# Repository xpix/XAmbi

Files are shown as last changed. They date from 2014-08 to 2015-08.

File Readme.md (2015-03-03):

XAmbi Network
----------------
By Frank Herrmann (xpixer@gmail.com)
<br/>
XAmbi Network with Atmel Attiny and RFM12B

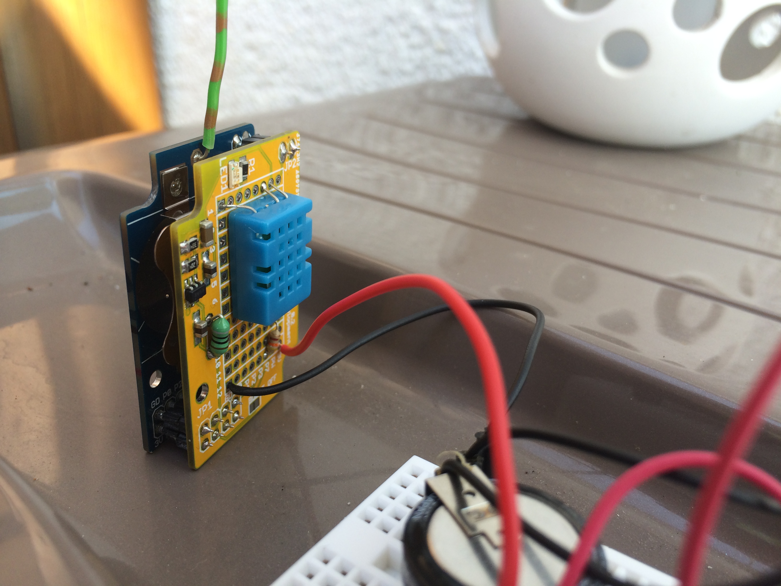
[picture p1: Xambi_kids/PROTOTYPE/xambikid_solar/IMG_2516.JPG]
XAmbi_kid_dht11


##Synopsis
The XAmbi Network system are a bunch of Sensor nodes and a Raspberry Gateway. This can control everything in your house and get the data in a nice Webinterface.
This is the Hardware section, here the Software part: [Webinterface](https://github.com/xpix/xambiserver) with MQTT Support. 

What do you need for the first start are follow components:
- a [RaspberryPi](http://en.wikipedia.org/wiki/Raspberry_Pi) with installed [git](http://en.wikipedia.org/wiki/Git_(software))
- a [Jeenode](http://jeelabs.net/projects/hardware/wiki/JeeNode) connected via USB or Serial to RPI
- one or more [xambi sensor](https://github.com/xpix/XAmbi/tree/master/Xambi_kids/xambikid_mainboard) nodes with an RFM12B Transceiver

##Features
- the xambi network system are very modular
- one Gateway with max 999 nodes
- very low bit rate for stable and long range communicaton via [Jeelib](http://jeelabs.net/pub/docs/jeelib/)
- sensor board a kind of breadboard to connect sensors very easy
- Boost to 3.3V on sensor board to get all energy from battery cell
- mainboard very small and standard sizes for normal enclousures

##Examples
- DHT11 [temperature and humidity Sensor](https://github.com/xpix/XAmbi/tree/master/Xambi_kids/xambikid_dht11)
- Dalles DS18B20 [Temperature Sensor](https://github.com/xpix/XAmbi/tree/master/Xambi_kids/xambikid_DS18B20)
- [Mailbox Sensor](https://github.com/xpix/XAmbi/tree/master/Xambi_kids/xambikid_mailbox) via infrared reflection
- Plant [Moisture Sensor](https://github.com/xpix/XAmbi/tree/master/Xambi_kids/xambikid_moisture)

##License
GPL 3.0. See License.txt file.

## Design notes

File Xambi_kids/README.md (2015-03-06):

XAmbi Kids
----------------
By Frank Herrmann (xpixer@gmail.com)
<br/>
XAmbi Network with Atmel Attiny and RFM12B

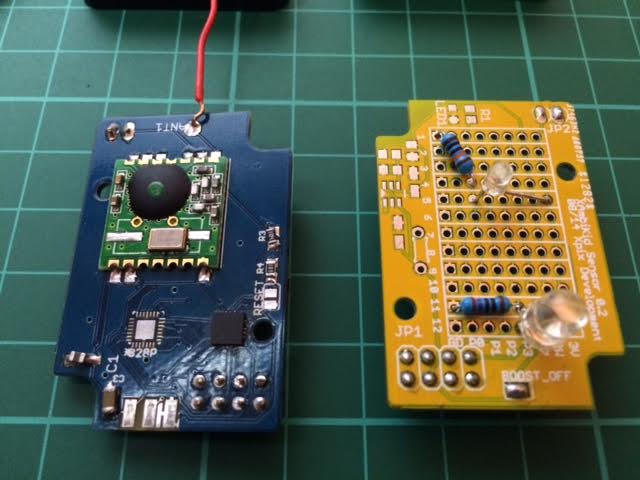
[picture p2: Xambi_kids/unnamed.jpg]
XAmbi_kid_mailbox


The XAmbi_Kids are sensors with an Attiny84 and a Transceiver RFM12B or for a cheaper solutuion with a infrared send led. 

##Features:

* small power consumtion. i.e. send every 5min a packet, run 1 year with a CR2032 battery cell
* send via serial with 2400 baud/s
* range up to ~15m in house
* range up to ~80m over the air
* cheap solution
* send via IR LED if you want and a revceiver exists
* small footprint (3x5cm)
* sensorboard with optional booster (1.5V => 3.3V or 5V)

##Hardware:

A xambi kid has 2 PCB's, they are stacked together. I call this [XAmbi-Mainboard](https://github.com/xpix/XAmbi/tree/master/Xambi_kids/xambikid_mainboard) and [XAmbi-Sensorboard](https://github.com/xpix/XAmbi/tree/master/Xambi_kids/xambikid_sensorboard). 
They are designed for a plastik enclouser [PDF Datasheet](https://cdn-reichelt.de/documents/datenblatt/C700/DS_1551G.pdf), they are standard and very cheap ~$2. We have to drill a hole for the antenna and thats all. 

##Software:

- DHT11 [temperature and humidity Sensor](https://github.com/xpix/XAmbi/tree/master/Xambi_kids/xambikid_dht11)
- Dalles DS18B20 [Temperature Sensor](https://github.com/xpix/XAmbi/tree/master/Xambi_kids/xambikid_DS18B20)
- [Mailbox Sensor](https://github.com/xpix/XAmbi/tree/master/Xambi_kids/xambikid_mailbox) via infrared reflection
- Plant [Moisture Sensor](https://github.com/xpix/XAmbi/tree/master/Xambi_kids/xambikid_moisture)

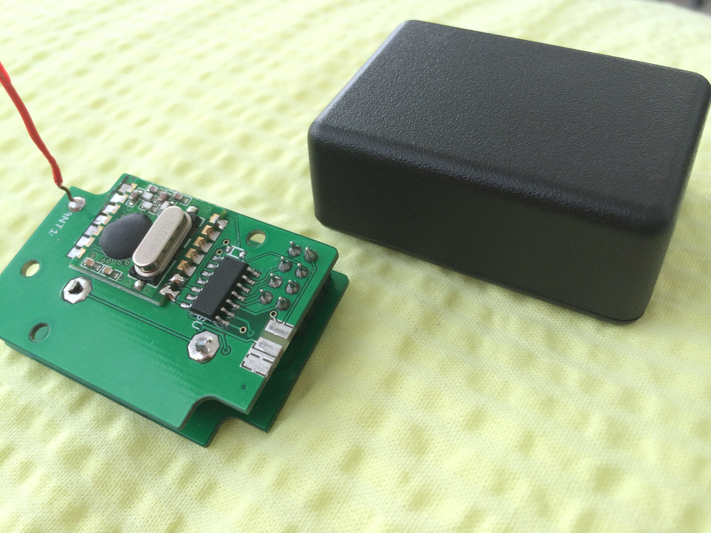
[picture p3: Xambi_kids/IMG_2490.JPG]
XAmbi_kid_dht11


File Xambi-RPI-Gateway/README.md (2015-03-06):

XAmbi Gateway for Raspberry PI
----------------
By Frank Herrmann (xpixer@gmail.com)
<br/>
RPI Shield with Atmega329P and RFM12B Transceiver 

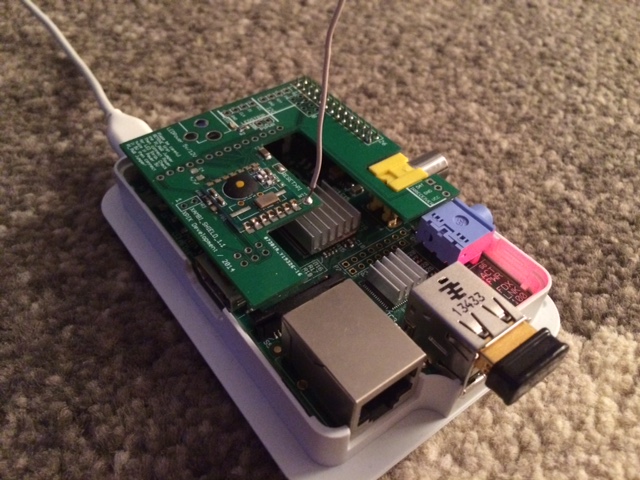
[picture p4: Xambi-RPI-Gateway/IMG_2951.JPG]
XAmbi_gateway


Here you find all the design for the Shield, on the pic you see the first Prototype. You can also connect a WS2812 LED Strip to install an Ambilight to your TV. But the first function from this board are a kind of [Jeenode](http://www.digitalsmarties.net/products/jeenode). 

* Solder an RF12B Board and Atmega with Quartz and other Components
* burn the fuses over ISCP and an Bootloader (Arduino UNO) to Atmega: [Tutorial](http://playground.arduino.cc/Learning/Burn168)
* Connect the board with an Raspberry PI
* Use the bootloader and burn the [simple receiver](https://github.com/xpix/XAmbi/tree/master/Xambi_kids/xambikid_simplereceiver) to the XAmbi Board
* connect via screen command and check for the "Init ..." text

You can use this Wiki: http://wiki.openenergymonitor.org/index.php?title=RFM12Pi_V2 they describe very good the steps to burn some firmware to an Arduno clone. This "Xambi-Gateway" are a arduino clone at the internal serial Line from Raspberry.

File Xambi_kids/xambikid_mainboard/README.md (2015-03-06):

XAmbi MainBoard
----------------
By Frank Herrmann (xpixer@gmail.com)
<br/>

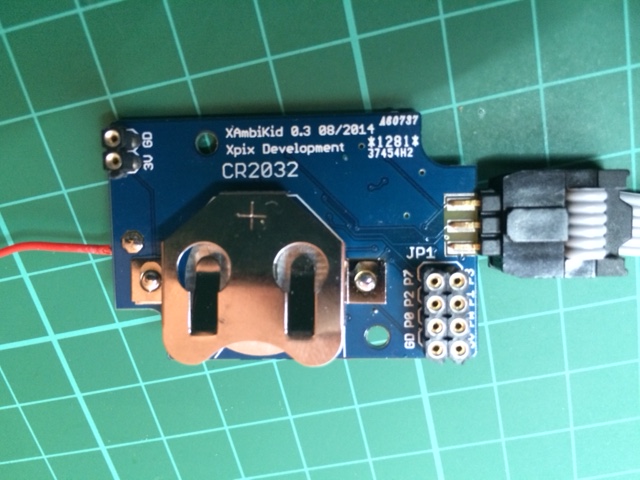
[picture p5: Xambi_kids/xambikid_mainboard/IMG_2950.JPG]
XAmbi-MainBoard

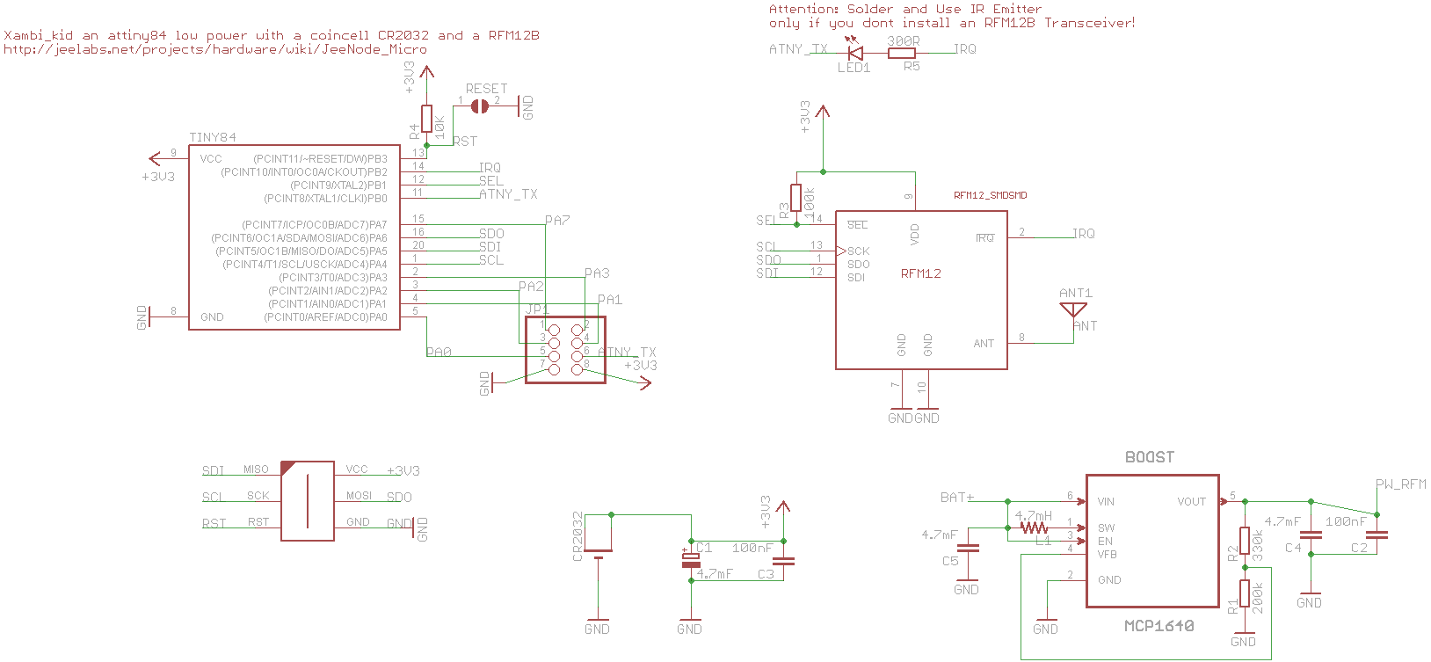
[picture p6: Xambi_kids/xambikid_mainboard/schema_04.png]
Schema 0.4

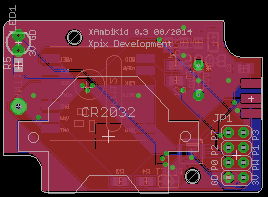
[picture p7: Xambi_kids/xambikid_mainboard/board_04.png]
Board 0.4


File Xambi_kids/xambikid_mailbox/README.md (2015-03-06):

XAmbi Mailbox IR Sensor
----------------
By Frank Herrmann (xpixer@gmail.com)
<br/>
XAmbi Network with Atmel Attiny and RFM12B

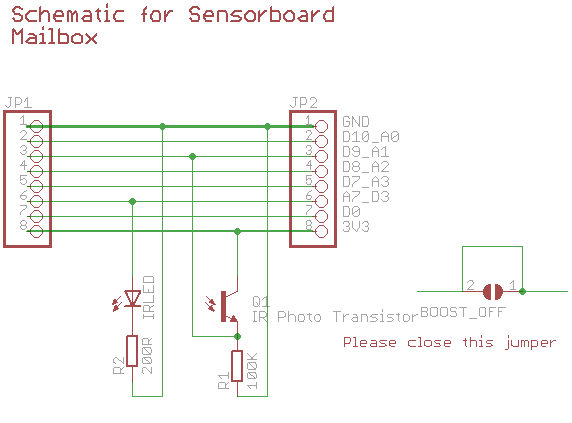
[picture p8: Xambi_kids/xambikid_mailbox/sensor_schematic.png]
XAmbi_moisture


##Synopsis
You can use this as mailbox Sensor. Via infred reflection to know is the box filled or empty.
This Sensor need Phototransistor and a IR LED. 
Please close the BOOST_OFF Jumper on Sensorboard.

##Youtube
* https://www.youtube.com/watch?v=9TAJDRMopDI

##License
GPL 3.0. See License.txt file.

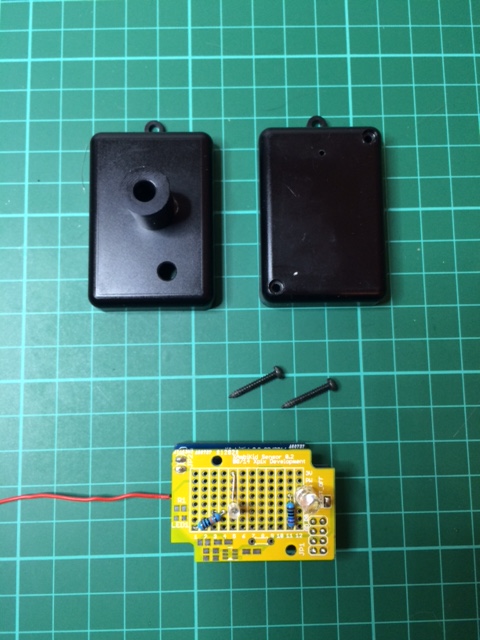
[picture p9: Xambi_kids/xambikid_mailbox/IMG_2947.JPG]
Enclousure
!

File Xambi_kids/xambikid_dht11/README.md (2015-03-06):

XAmbi Temperature/Humidity DHT11 Sensor
----------------
By Frank Herrmann (xpixer@gmail.com)
<br/>
XAmbi Network with Atmel Attiny and RFM12B

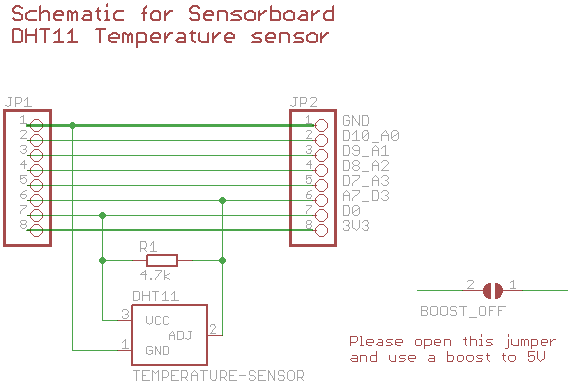
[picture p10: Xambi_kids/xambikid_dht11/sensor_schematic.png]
XAmbi_moisture


##Synopsis
You can use this Sensor as temperature and humidity Sensor. 
This Sensor need only one DHT11 sensor and one resistor. 
Please let open the BOOST_OFF Jumper on Sensorboard and use a booster to 5V.

##License
GPL 3.0. See License.txt file.

DHT11!

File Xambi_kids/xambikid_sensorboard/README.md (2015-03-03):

XAmbi SensorBoard
----------------
By Frank Herrmann (xpixer@gmail.com)
<br/>

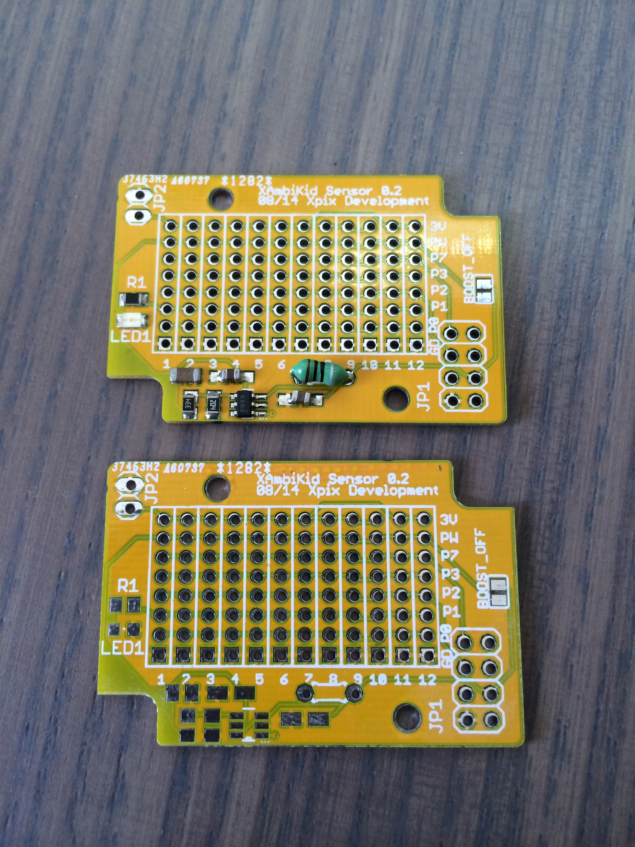
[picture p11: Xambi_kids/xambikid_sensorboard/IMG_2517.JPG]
XAmbi-Sensorboard


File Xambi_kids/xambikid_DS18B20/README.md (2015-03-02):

XAmbi Temperature DS18B20 Sensor
----------------
By Frank Herrmann (xpixer@gmail.com)
<br/>
XAmbi Network with Atmel Attiny and RFM12B

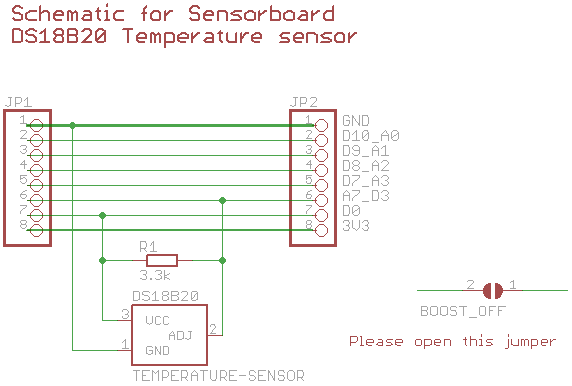
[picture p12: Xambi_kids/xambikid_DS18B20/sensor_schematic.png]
XAmbi_moisture


##Synopsis
You can use this Sensor as temperature Sensor. 
This Sensor need only one DS18B20 sensor and one resistor. 
Please let open the BOOST_OFF Jumper on Sensorboard.

##License
GPL 3.0. See License.txt file.

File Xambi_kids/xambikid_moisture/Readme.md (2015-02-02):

XAmbi Moisture Sensor
----------------
By Frank Herrmann (xpixer@gmail.com)
<br/>
XAmbi Network with Atmel Attiny and RFM12B

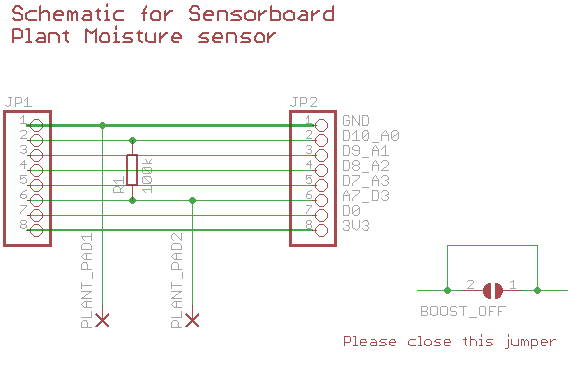
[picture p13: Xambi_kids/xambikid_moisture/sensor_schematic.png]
XAmbi_moisture


##Synopsis
You can use this Sensor as Plant moisture Sensor. This Sensor need only one 100K resistor and some strong wires as Sensorpads for the plant. Please close the BOOST_OFF Jumper on Sensorboard.

##License
GPL 3.0. See License.txt file.

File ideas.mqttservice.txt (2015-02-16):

own MQTT Service to map topics to groups:
-----------------------------------------

* all called topics try to remap
* send remapped topic to mqtt broker

API
-----------------------------------------
List groups or sensors
   /remap/list => /groups
   /remap/list => /groups/FOO
   
Add sensor 111 to group: FOO
   /remap/add/FOO => /sensors/111/power
   /remap/add/FOO => /sensors/111

Delete Sensor 111 from group: FOO
   /remap/remove/FOO => /sensors/111/power
   /remap/remove/FOO => /sensors/111

Move Sensor(s) 111 to FOO:   
   /remap/move/FOO => /sensors/111/power
   /remap/move/FOO => /sensors/111

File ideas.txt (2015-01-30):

Xambi - media shield for raspberry pi
=====================================

DESCRIPTION:

xambi are a shield for raspberry pi. the name xambi it\'s a word game between my pseudonym "xpix" and "ambilight".

FEATURES:

* Ambilight connects for WS2811 and others
* 5V-12V connect for Ambilight
* Infrared receiver
* RF link for 433 mHz power plugins 
* use RFM12B 433MHZ Modules 
 
WS2811/WS2812
----------------------
   * user use stripes with 5V or 12V

RF Transmitter 433 mHz
----------------------
   * http://technerd.de/raspberry-pi-funksteckdose-mit-rf-link-transmitter-wrl-10534-schalten_604.html
   * http://raspberrypiguide.de/howtos/powerpi-raspberry-pi-haussteuerung/ 
   * http://hempel.dd-dns.de/cms/index.php/fhem/articles/intertechno-steckdosen-mit-raspberry-pi-aus-fhem-ansteuern.html
   * http://emoncms.org/ (Energy Monitor)

   * http://openenergymonitor.org/emon/emonbase/raspberrypi
   * http://wiki.openenergymonitor.org/index.php?title=RFM12Pi_V2
      create a test board with Atmega328/ICSP/RFM12B
      upload this sketch: 
         https://github.com/mharizanov/RFM2Pi/blob/master/firmware/RF12_Demo_atmega328/RF12_Demo_atmega328.ino
      create small node with temp and humidity

Support rfm as kernel Modules
-----------------------------
   * http://l0l.org.uk/2013/11/rfm12b-linking-jeenode-micro-raspberry-pi/
   * https://github.com/abouillot/HomeAutomation/tree/master/piGateway
      - use RPI only with RFM12 and kernel Modules
      - rewrite serial to support this module
      - call c prg from perl serial.pl and get every row

RFM Transceiver with Atmega or Attiny
-------------------------------------
* http://wiki.openenergymonitor.org/index.php?title=RFM12Pi_V2

Reset in RP
---------------
avrdude -patmega328p -carduino -P /dev/ttyATMA0 -b57600 -v

Boards.txt Segement:
---------------
##############################################################
atmega328bb.name=ATmega328 on a breadboard (3.3v, 8 MHz internal clock)

atmega328bb.upload.maximum_size=30720
atmega328bb.upload.protocol=usbasp
atmega328bb.upload.using=usbasp

atmega328bb.bootloader.tool=avrdude
atmega328bb.bootloader.low_fuses=0xE2
atmega328bb.bootloader.high_fuses=0xD8
atmega328bb.bootloader.extended_fuses=0x07
atmega328bb.bootloader.path=atmega
atmega328bb.bootloader.file=atmega/ATmegaBOOT_168_atmega328_pro_8MHz.hex
atmega328bb.bootloader.unlock_bits=0x3F
atmega328bb.bootloader.lock_bits=0x0F

atmega328bb.build.mcu=atmega328p
atmega328bb.build.f_cpu=8000000L
atmega328bb.build.core=arduino
atmega328bb.build.variant=standard
##############################################################

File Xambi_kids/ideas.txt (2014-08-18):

small low power transmitter in 433.92 MHz
=========================================
* http://mbed.org/users/4180_1/notebook/ir-and-rf-remote-controls/

Complete template and schematic for a small Atmega328 with RFM12B
* http://robotikhardware.de/download/RN-MikroFunk_1.7.pdf

A LOT of examples for xambi_kids (temp, switch, ...)
* http://nathan.chantrell.net/tinytx-wireless-sensor/
* receive end: 
   http://openenergymonitor.org/emon/emonbase/raspberrypi
   See also in Xambi/ideas.txt

Store:
* http://www.digitalsmarties.net/products/rfm12b-433-mhz - 2,95 Euro in 6Pack
* http://rf-store.com/index.php?s_phr=rfm&pv=search&view=2 - 3,97 Euro
Attiny84 Programmadapter
* http://www.ebay.de/itm/ATtiny24A-SSU-ATtiny24-ATtiny44-ATtiny84-AVR-SOIC14-150-mil-Programming-Adapter-/261012681784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

Notes Haka:
   * Mosfet ist falsch herum, überbrücken
      http://www.dz863.com/datasheet-811350663-BSS84_P-channel-Enhancement-Mode-Mosfet/
   * R3 am Reset erst einmal weglassen

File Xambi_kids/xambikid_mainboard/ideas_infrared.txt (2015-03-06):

Transfer Data via infrared
--------------------------
* Take Hardware serial pin and send via IR Diode and IR Receiver TSOP
   https://tthheessiiss.wordpress.com/2009/08/05/dirt-cheap-wireless/
   http://forum.arduino.cc/index.php?topic=10555.0 (more power for IR LED)
   http://dangerousprototypes.com/2009/08/26/easy-infrared-data-link/

* first build works with TSOP1138

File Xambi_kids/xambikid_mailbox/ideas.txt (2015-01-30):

# Mailbox Sensor

* measure the refelction between IR sensor to wall and back
* sensor knows between full and empty, cuz reflection changed
* check every minute 

http://www.instructables.com/id/Make-an-Attiny13-based-IR-proximity-sensor-for-2/?ALLSTEPS
http://letsmakerobots.com/content/how-use-infrared-receiver-sensors-collision-avoidance

* library
http://forum.arduino.cc/index.php?topic=101156.0

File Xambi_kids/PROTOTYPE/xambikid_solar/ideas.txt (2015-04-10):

Ziel:
----
- autarkes Sensorboard ohne externe Stromversorgung

Aufbau:
------
- Zusätzliches Board, das sich aufstecken lässt.
- Anschluss zu VCC vom mainboard
- ein oder zwei Golgcaps
- Anschluss für Solarpanel

Solar in verbindung mit CR2032 (aufladbar)
--------------------
- http://www.instructables.com/answers/Can-I-hook-a-3v-solar-panel-up-to-charge-a-3v-lith/

Solar mit Goldcaps:
-------------------
- https://www.sparkfun.com/news/1131
- http://jeelabs.org/tag/solar/

Bestellt:
------------------
- http://www.pollin.de/shop/dt/NzE2OTU4OTk-/Bauelemente_Bauteile/Aktive_Bauelemente/Dioden/Dioden_Packung_mit_10_Stueck.html
- http://www.pollin.de/shop/dt/MzQ1OTg3OTk-/Bauelemente_Bauteile/Passive_Bauelemente/Elkos_Goldcaps/Gold_Cap_PANASONIC_EECS5R5H105.html

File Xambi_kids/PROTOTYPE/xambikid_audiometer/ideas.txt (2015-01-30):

Ziel:
----
- Mikrofon sensor board das die Umgebungslautstärke misst

Aufbau:
------
- Mikrofon mit vorverstaärker am A/D Pin.
- Misst alle 500ms die Umgebungslautstärke und sendet alle X Minuten eine Zusammenfassung
- z.B. "nodeid power 521 510 500 255 300 278" (durchscnitt alle 10 Sekunden mit senden jeder minute)

Artikel:
------------------
- http://rn-wissen.de/wiki/index.php/CCRP5#Mikrofon

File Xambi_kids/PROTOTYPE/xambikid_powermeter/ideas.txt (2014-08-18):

# Power Sensor

* measure the refelction from silver wheel in power meter

http://www.dirk-melchers.de/wiki/arduino/strom-messung/stromtransmitter

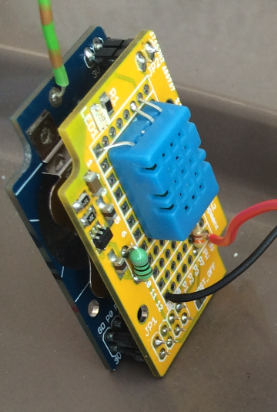
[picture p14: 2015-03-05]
Xambi_kids/xambikid_dht11/xambi_dht11.PNG

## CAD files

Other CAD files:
Xambi-RPI-Gateway/xambi_2.0-tcream.dxf
Xambi_kids/xambikid_mainboard/xkid_0.4-tcream.dxf
Xambi_kids/xambikid_mini_pro/Arduino-Pro-Mini-xkid-bcream.dxf
Xambi_kids/xambikid_sensorboard/xkid_sensor_0.2-tcream.dxf
Xambi-RPI-Gateway/xambi_2.0-bcream.dxf
Xambi_kids/xambikid_mainboard/xkid_0.4-bcream.dxf
Xambi_kids/xambikid_mini_pro/Arduino-Pro-Mini-xkid-tcream.dxf
Xambi-RPI-Gateway/xambi_1.1-tcream.dxf
Xambi-RPI-Gateway/xambi_1.1-bcream.dxf
Xambi-RPI-Gateway/xambi_1.0-tcream.dxf
Xambi-RPI-Gateway/xambi_1.0-bcream.dxf

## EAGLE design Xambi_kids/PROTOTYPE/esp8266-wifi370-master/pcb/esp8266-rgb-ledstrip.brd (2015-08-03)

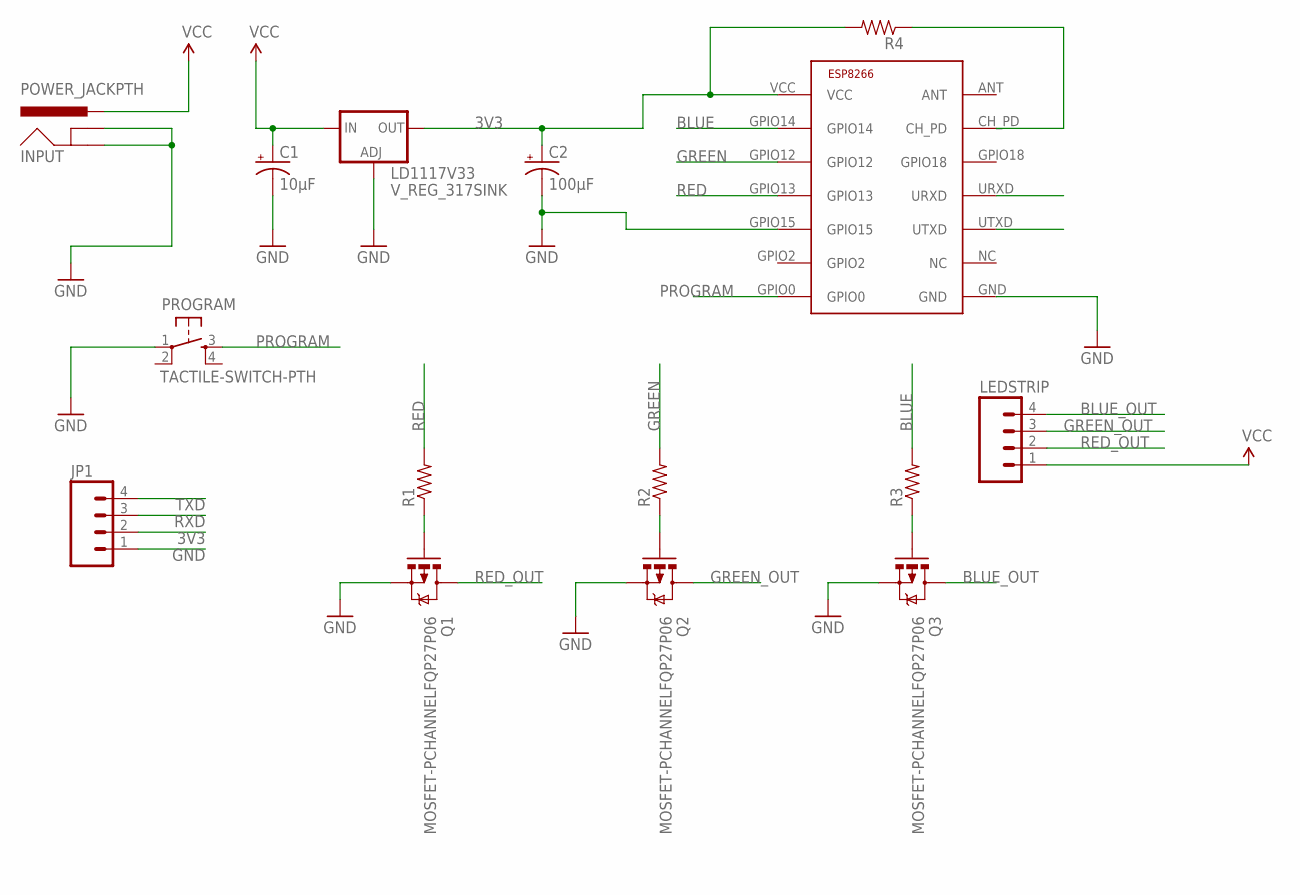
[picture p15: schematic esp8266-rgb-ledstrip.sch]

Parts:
C1: 10µF; CPOL-RADIAL-10UF-25V
C2: 100µF; CPOL-RADIAL-100UF-25V
INPUT: POWER_JACKPTH; POWER_JACK_PTH
JP1: M04PTH; 1X04
LD1117V33: V_REG_317SINK; TO220-ADJ
LEDSTRIP: M04PTH; 1X04
PROGRAM: TACTILE-SWITCH-PTH; TAC-SWITCH-PTH
Q1, Q2, Q3: MOSFET-PCHANNELFQP27P06; TO220V
R1, R2, R3, R4: RESISTORAXIAL-0.3; AXIAL-0.3
U$1: ESP8266-03; ESP-03

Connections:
3V3: C2.1 (+), JP1.2, LD1117V33.OUT, R4.P$2 (2), U$1.VCC
BLUE: R3.P$2 (2), U$1.GPIO14
BLUE_OUT: LEDSTRIP.4, Q3.2 (D)
BLUE_R: Q3.1 (G), R3.P$1 (1)
GND: C1.2 (-), C2.2 (-), INPUT.GND, INPUT.GNDBREAK, JP1.1, LD1117V33.ADJ, PROGRAM.1, Q1.3 (S), Q2.3 (S), Q3.3 (S), U$1.GND, U$1.GPIO15
GREEN: R2.P$2 (2), U$1.GPIO12
GREEN_OUT: LEDSTRIP.3, Q2.2 (D)
GREEN_R: Q2.1 (G), R2.P$1 (1)
unnamed: R4.P$1 (1), U$1.CH_PD
PROGRAM: PROGRAM.3, U$1.GPIO0
RED: R1.P$2 (2), U$1.GPIO13
RED_OUT: LEDSTRIP.2, Q1.2 (D)
RED_R: Q1.1 (G), R1.P$1 (1)
RXD: JP1.3, U$1.URXD
TXD: JP1.4, U$1.UTXD
VCC: C1.1 (+), INPUT.PWR, LD1117V33.IN, LEDSTRIP.1

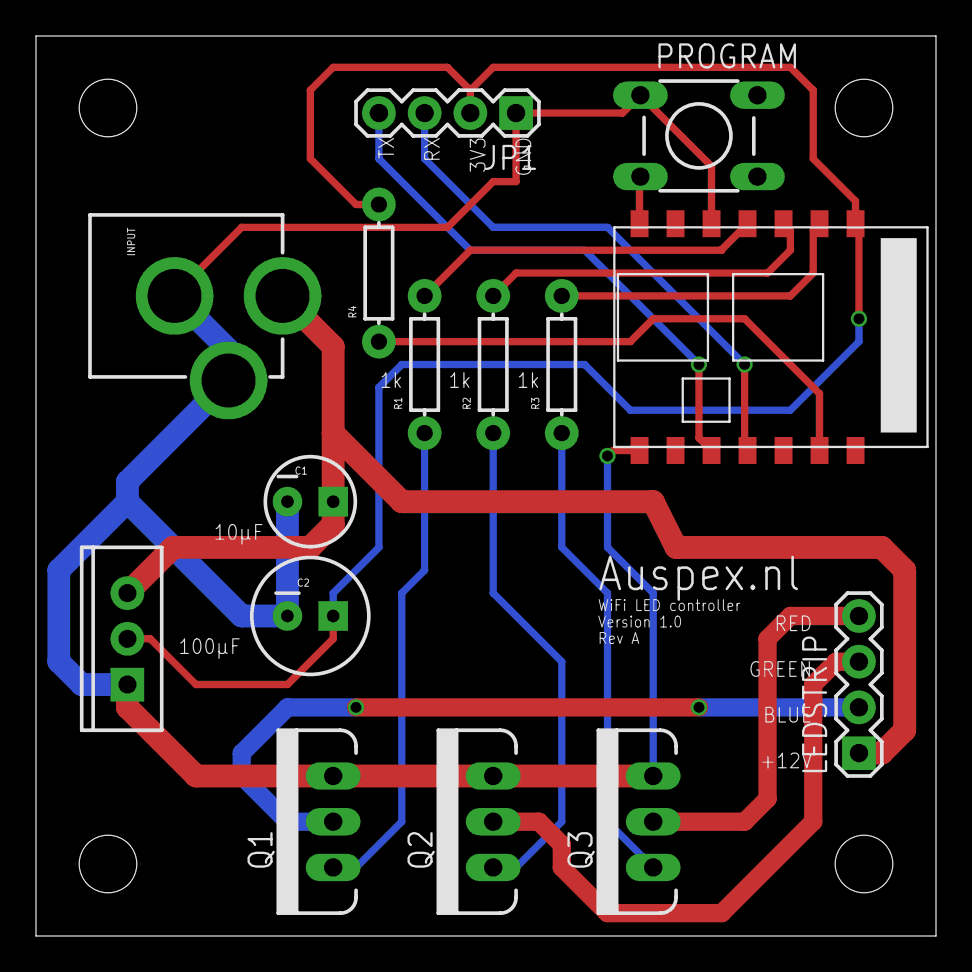
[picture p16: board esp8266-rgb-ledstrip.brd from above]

Board: 2 copper layers, 50.0 x 50.0 mm, 15 parts (0 on the bottom side), 16 nets.

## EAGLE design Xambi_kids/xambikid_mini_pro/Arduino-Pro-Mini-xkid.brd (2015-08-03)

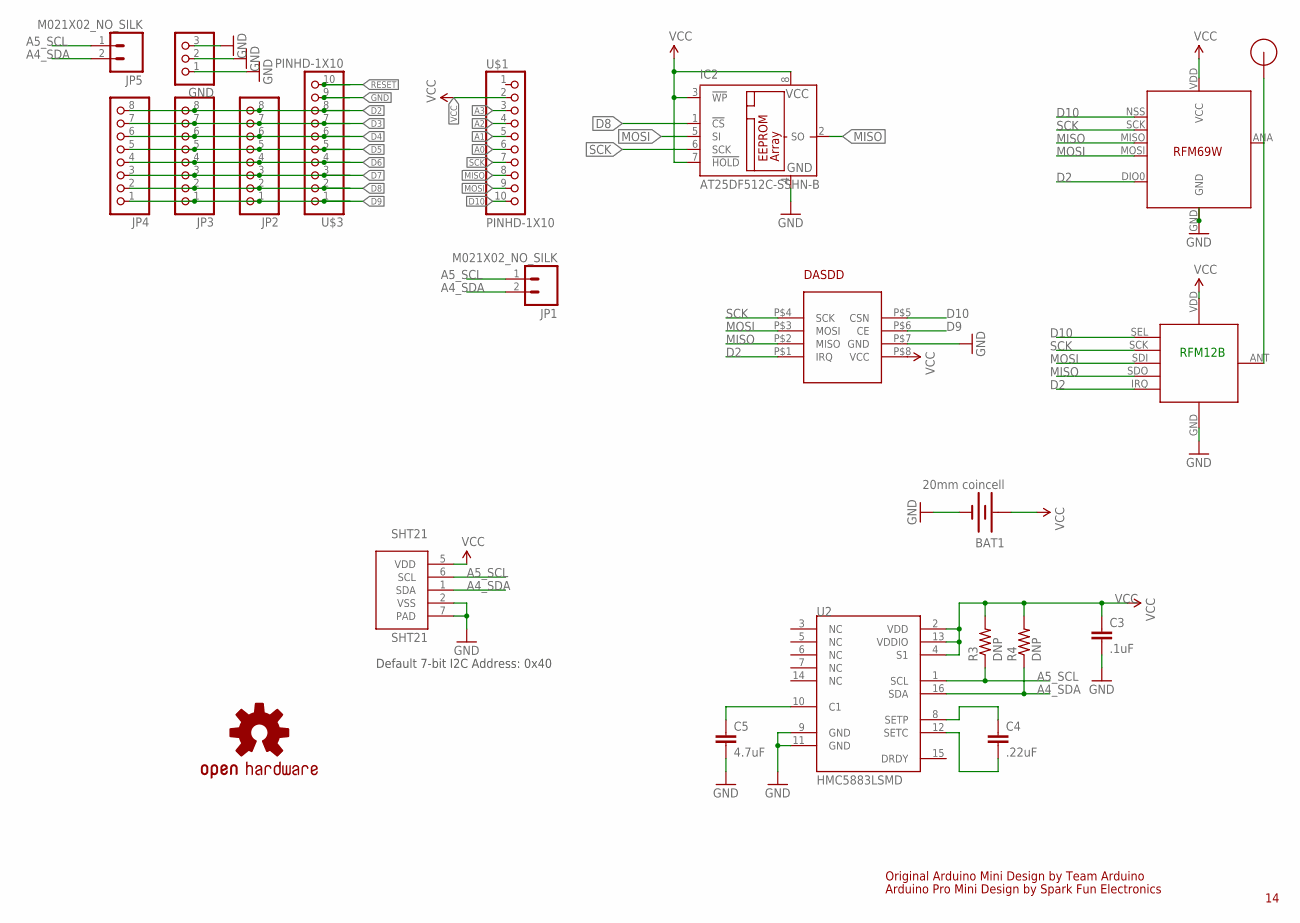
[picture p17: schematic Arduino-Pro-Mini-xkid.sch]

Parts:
BAT1: 20mm coincell; BATTCON_20MM_4LEGS
C3: .1uF; 0603-CAP
C4: .22uF; 0603-CAP
C5: 4.7uF; 0603-CAP
DASDD: NRF24L01+_1.27; NRF24L01_1.27
GND: PINHD-1X3; 1X03
IC2: AT25DF512C-SSHN-B; SO-08
JP1, JP5: M021X02_NO_SILK; 1X02_NO_SILK
JP2, JP3, JP4: PINHD-1X8CLEANBIG; 1X08-CLEANBIG
LOGO1: OSHW-LOGOM; OSHW-LOGO-M
R3, R4: DNP; 0603-RES
RFM12B: RFM12B_MINPADS; RFM12B-MINPADS
RFM69W: RFM69; RFM69W-MINPADS
SHT21: SHT21; SEN-SENSIRION-SHT2X
U2: HMC5883LSMD; 16LPCC
U$1, U$3: PINHD-1X10; 1X10-BIG
U$4: RFM12B_ANTENNA; RFM12B-ANTENNA

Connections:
A0: U$1.6
A1: U$1.5
A2: U$1.4
A3: U$1.3
A4_SDA: JP1.2, JP5.2, R4.1, SHT21.1 (SDA), U2.16 (SDA)
A5_SCL: JP1.1, JP5.1, R3.1, SHT21.6 (SCL), U2.1 (SCL)
D2: DASDD.P$1 (IRQ), JP2.8, JP3.8, JP4.8, RFM12B.IRQ, RFM69W.DIO0, U$3.8
D3: JP2.7, JP3.7, JP4.7, U$3.7
D4: JP2.6, JP3.6, JP4.6, U$3.6
D5: JP2.5, JP3.5, JP4.5, U$3.5
D6: JP2.4, JP3.4, JP4.4, U$3.4
D7: JP2.3, JP3.3, JP4.3, U$3.3
D8: IC2.1 (!CS), JP2.2, JP3.2, JP4.2, U$3.2
D9: DASDD.P$6 (CE), JP2.1, JP3.1, JP4.1, U$3.1
D10: DASDD.P$5 (CSN), RFM12B.SEL, RFM69W.NSS (SEL), U$1.10
GND: BAT1.2 (-), C3.2, C5.2, DASDD.P$7 (GND), GND.1, GND.2, GND.3, IC2.4 (GND), RFM12B.GND, RFM69W.GND, SHT21.2 (VSS), SHT21.7 (PAD), U2.9 (GND), U2.11 (GND), U$3.9
MISO: DASDD.P$2 (MISO), IC2.2 (SO), RFM12B.SDO (SDO/MISO), RFM69W.MISO, U$1.8
MOSI: DASDD.P$3 (MOSI), IC2.5 (SI), RFM12B.SDI (SDI/MOSI), RFM69W.MOSI, U$1.9
unnamed: RFM12B.ANT, RFM69W.ANA (ANT), U$4.P$1
unnamed: C4.1, U2.8 (SETP)
unnamed: C4.2, U2.12 (SETC)
unnamed: C5.1, U2.10 (C1)
RESET: U$3.10
SCK: DASDD.P$4 (SCK), IC2.6 (SCK), RFM12B.SCK, RFM69W.SCK, U$1.7
VCC: BAT1.1 (+), C3.1, DASDD.P$8 (VCC), IC2.3 (!WP), IC2.7 (!HOLD), IC2.8 (VCC), R3.2, R4.2, RFM12B.VDD, RFM69W.VDD (VCC), SHT21.5 (VDD), U2.2 (VDD), U2.4 (S1), U2.13 (VDDIO), U$1.2

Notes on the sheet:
Original Arduino Mini Design by Team Arduino
Arduino Pro Mini Design by Spark Fun Electronics
Default 7-bit I2C Address: 0x40
RFM12B

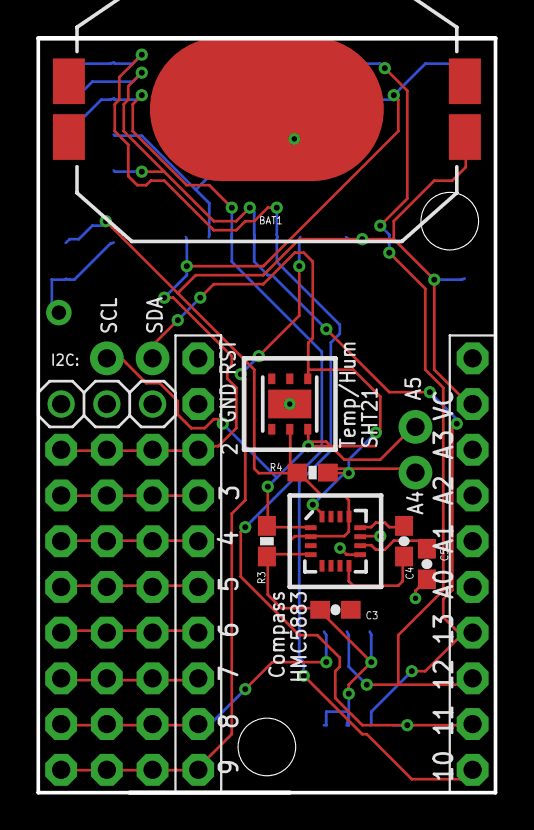
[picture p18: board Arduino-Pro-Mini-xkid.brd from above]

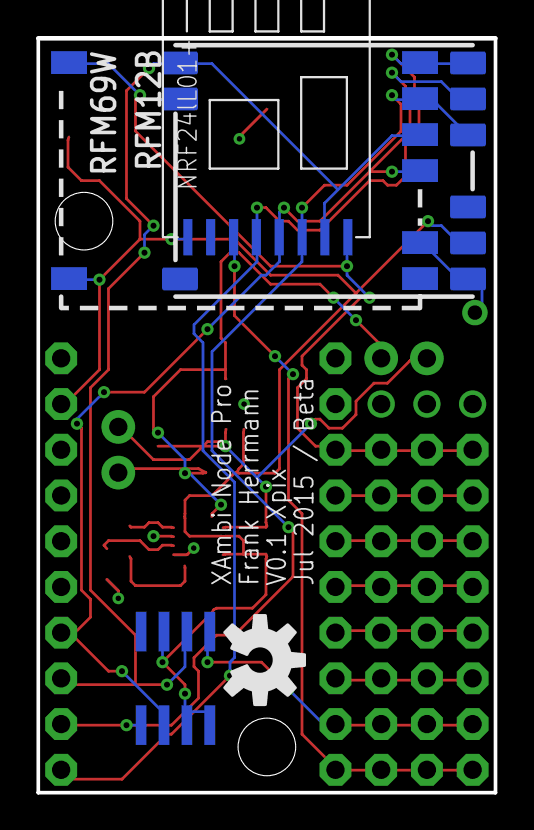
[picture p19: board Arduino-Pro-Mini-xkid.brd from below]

Board: 2 copper layers, 25.4 x 41.9 mm, 22 parts (5 on the bottom side), 20 nets.

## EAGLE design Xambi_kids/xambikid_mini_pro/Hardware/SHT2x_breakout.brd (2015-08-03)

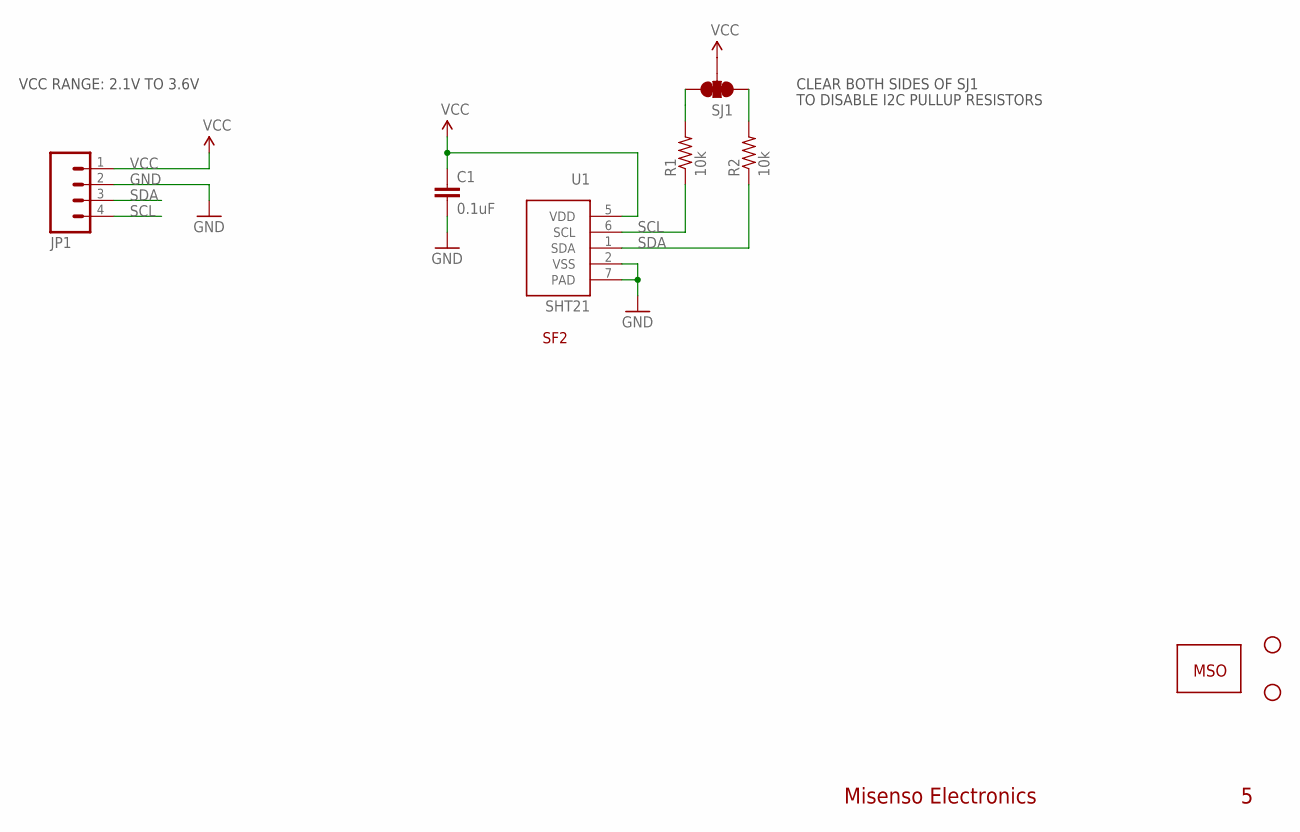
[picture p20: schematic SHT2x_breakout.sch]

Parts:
C1: 0.1uF; 0402-CAP
JP1: M04PTH; 1X04
R1, R2: 10k; 0402-RES
SJ1: SOLDERJUMPER_2WAYPASTE1&2&3; SJ_3_PASTE1&2&3
STANDOFF1, STANDOFF2: STAND-OFF
U1: SHT21; SEN-SENSIRION-SHT2X
U$2: MSO-LOGO
U$3: MISC-SENSIRION-SF2

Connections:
GND: C1.2, JP1.2, U1.2 (VSS), U1.7 (PAD)
unnamed: R1.2, SJ1.3
unnamed: R2.2, SJ1.1
SCL: JP1.4, R1.1, U1.6 (SCL)
SDA: JP1.3, R2.1, U1.1 (SDA)
VCC: C1.1, JP1.1, SJ1.2, U1.5 (VDD)

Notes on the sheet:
Misenso Electronics
CLEAR BOTH SIDES OF SJ1
TO DISABLE I2C PULLUP RESISTORS
VCC RANGE: 2.1V TO 3.6V

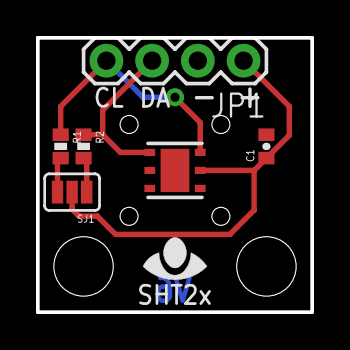
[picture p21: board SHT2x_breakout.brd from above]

Board: 2 copper layers, 15.2 x 15.2 mm, 10 parts (0 on the bottom side), 6 nets.

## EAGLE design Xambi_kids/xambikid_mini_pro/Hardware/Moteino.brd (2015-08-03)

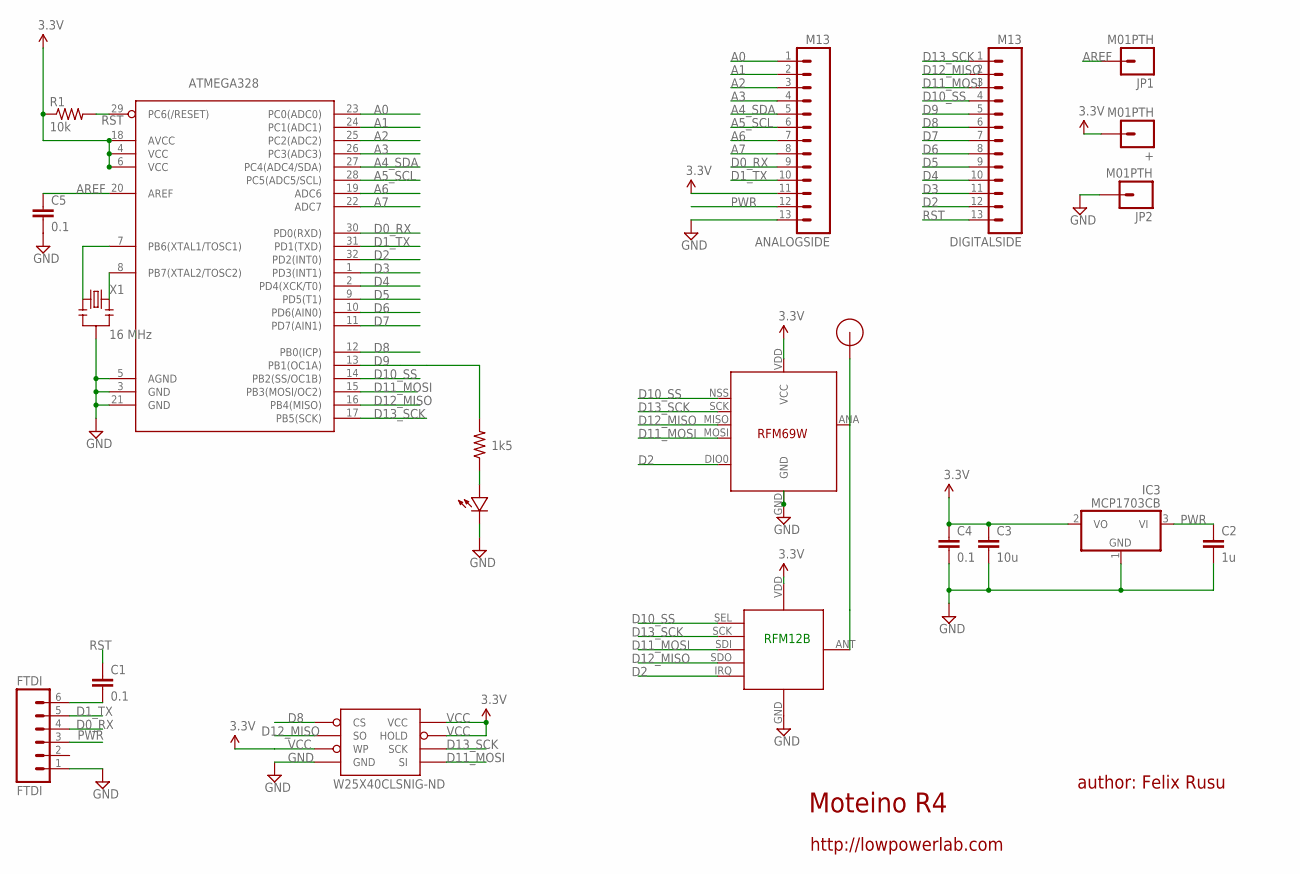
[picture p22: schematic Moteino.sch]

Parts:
+: M01PTH; 1X01
ANALOGSIDE: M13; 1X13
ATMEGA328: ATMega-328; TQFP32-08
C1, C4, C5: 0.1; 0603-CAP
C2: 1u; 0603-CAP
C3: 10u; 0805-CAP
DIGITALSIDE: M13; 1X13
FTDI: FTDI; 1X06
IC3: MCP1703CB; SOT23
JP1, JP2: M01PTH; 1X01
R1: 10k; 0603-RES
R2: 1k5; 0603-RES
RFM12B: RFM12B_MINPADS; RFM12B-MINPADS
U$1: RFM12B_ANTENNA; RFM12B-ANTENNA
U$2: LED0603; 0603-LED
U$5: RFM69; RFM69W-MINPADS
W25X40CLSNIG-ND: AT25F512BWIDE_5.3MM; SO08WIDE
X1: 16 MHz; RESONATOR-SMD

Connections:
A0: ANALOGSIDE.1, ATMEGA328.23 (PC0(ADC0))
A1: ANALOGSIDE.2, ATMEGA328.24 (PC1(ADC1))
A2: ANALOGSIDE.3, ATMEGA328.25 (PC2(ADC2))
A3: ANALOGSIDE.4, ATMEGA328.26 (PC3(ADC3))
A4_SDA: ANALOGSIDE.5, ATMEGA328.27 (PC4(ADC4/SDA))
A5_SCL: ANALOGSIDE.6, ATMEGA328.28 (PC5(ADC5/SCL))
A6: ANALOGSIDE.7, ATMEGA328.19 (ADC6)
A7: ANALOGSIDE.8, ATMEGA328.22 (ADC7)
AREF: ATMEGA328.20 (AREF), C5.1, JP1.1
D0_RX: ANALOGSIDE.9, ATMEGA328.30 (PD0(RXD)), FTDI.4
D1_TX: ANALOGSIDE.10, ATMEGA328.31 (PD1(TXD)), FTDI.5
D2: ATMEGA328.32 (PD2(INT0)), DIGITALSIDE.12, RFM12B.IRQ, U$5.DIO0
D3: ATMEGA328.1 (PD3(INT1)), DIGITALSIDE.11
D4: ATMEGA328.2 (PD4(XCK/T0)), DIGITALSIDE.10
D5: ATMEGA328.9 (PD5(T1)), DIGITALSIDE.9
D6: ATMEGA328.10 (PD6(AIN0)), DIGITALSIDE.8
D7: ATMEGA328.11 (PD7(AIN1)), DIGITALSIDE.7
D8: ATMEGA328.12 (PB0(ICP)), DIGITALSIDE.6, W25X40CLSNIG-ND.1 (CS)
D9: ATMEGA328.13 (PB1(OC1A)), DIGITALSIDE.5, R2.2
D10_SS: ATMEGA328.14 (PB2(SS/OC1B)), DIGITALSIDE.4, RFM12B.SEL, U$5.NSS (SEL)
D11_MOSI: ATMEGA328.15 (PB3(MOSI/OC2)), DIGITALSIDE.3, RFM12B.SDI (SDI/MOSI), U$5.MOSI, W25X40CLSNIG-ND.5 (SI)
D12_MISO: ATMEGA328.16 (PB4(MISO)), DIGITALSIDE.2, RFM12B.SDO (SDO/MISO), U$5.MISO, W25X40CLSNIG-ND.2 (SO)
D13_SCK: ATMEGA328.17 (PB5(SCK)), DIGITALSIDE.1, RFM12B.SCK, U$5.SCK, W25X40CLSNIG-ND.6 (SCK)
GND: ANALOGSIDE.13, ATMEGA328.3 (GND), ATMEGA328.5 (AGND), ATMEGA328.21 (GND), C2.2, C3.2, C4.2, C5.2, FTDI.1, IC3.1 (GND), JP2.1, RFM12B.GND, U$2.MINUS, U$5.GND, W25X40CLSNIG-ND.4 (GND), X1.2
unnamed: ATMEGA328.7 (PB6(XTAL1/TOSC1)), X1.1
unnamed: R2.1, U$2.PLUS
unnamed: RFM12B.ANT, U$1.P$1, U$5.ANA (ANT)
unnamed: C1.2, FTDI.6
unnamed: ATMEGA328.8 (PB7(XTAL2/TOSC2)), X1.3
PWR: ANALOGSIDE.12, C2.1, FTDI.3, IC3.3 (VI)
RST: ATMEGA328.29 (PC6(/RESET)), C1.1, DIGITALSIDE.13, R1.2
VCC: +.1, ANALOGSIDE.11, ATMEGA328.4 (VCC), ATMEGA328.6 (VCC), ATMEGA328.18 (AVCC), C3.1, C4.1, IC3.2 (VO), R1.1, RFM12B.VDD, U$5.VDD (VCC), W25X40CLSNIG-ND.3 (WP), W25X40CLSNIG-ND.7 (HOLD), W25X40CLSNIG-ND.8 (VCC)

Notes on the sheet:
Moteino R4
author: Felix Rusu
http://lowpowerlab.com
RFM12B

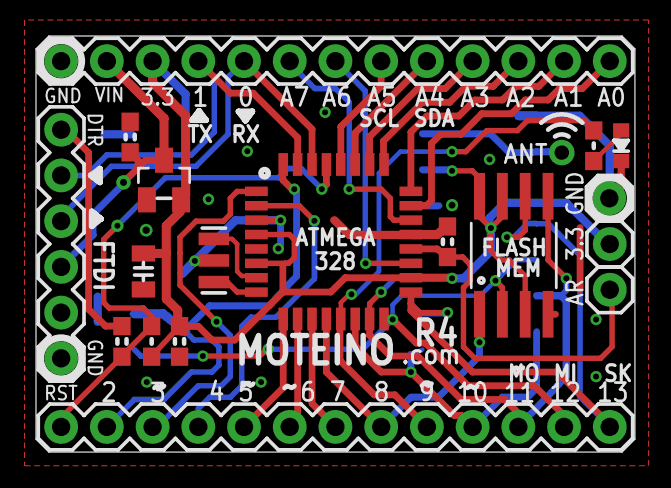
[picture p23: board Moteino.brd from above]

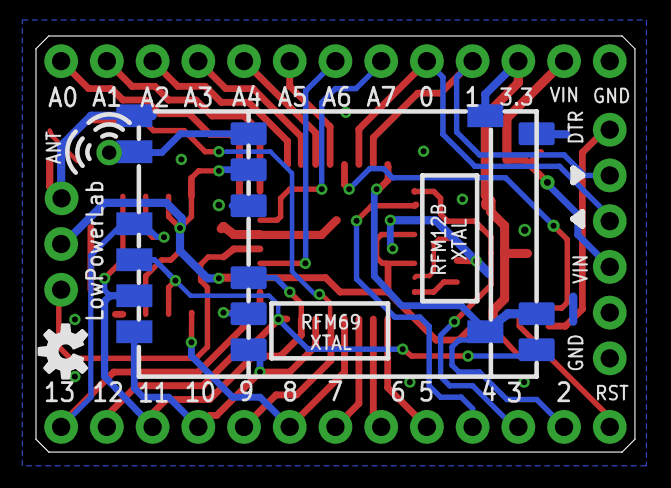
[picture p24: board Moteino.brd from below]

Board: 2 copper layers, 33.3 x 23.1 mm, 22 parts (3 on the bottom side), 32 nets.

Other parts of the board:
U$3: OSHW-LOGO-S

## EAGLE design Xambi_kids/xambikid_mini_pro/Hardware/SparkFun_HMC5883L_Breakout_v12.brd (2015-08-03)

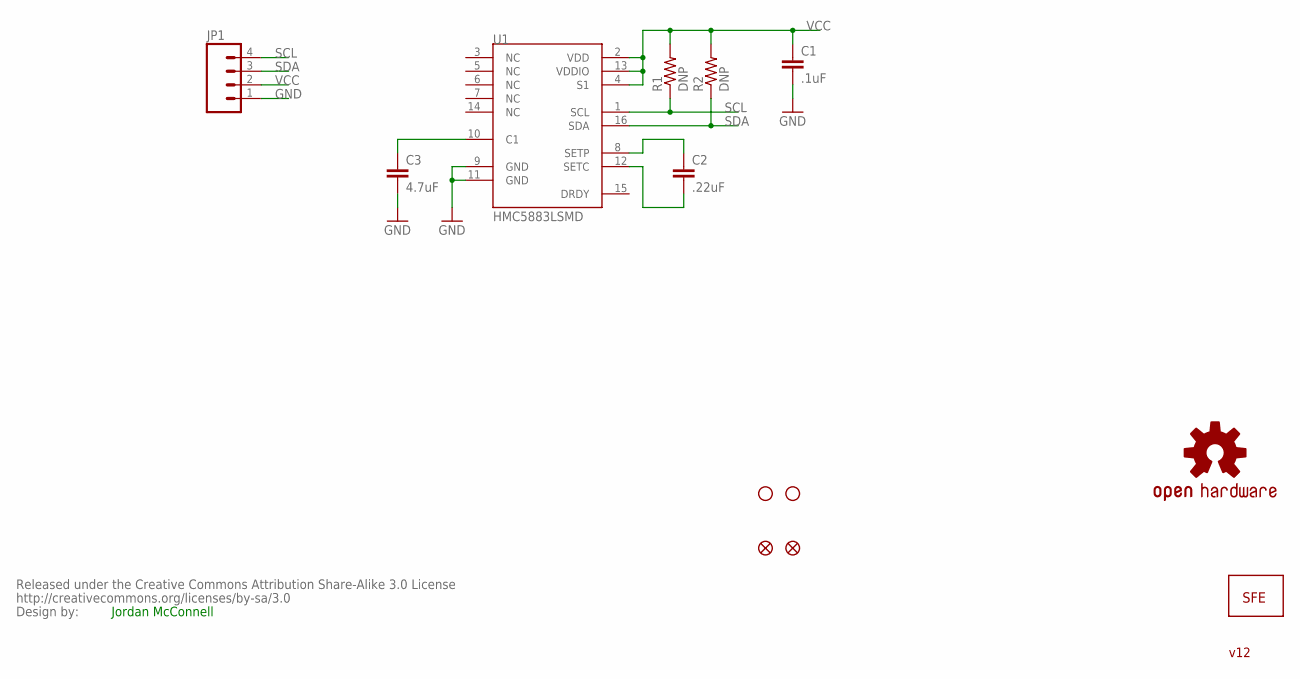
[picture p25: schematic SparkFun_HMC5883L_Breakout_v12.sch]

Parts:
C1: .1uF; 0402-CAP
C2: .22uF; 0402-CAP
C3: 4.7uF; 0402-CAP
JP1: M04PTH; 1X04
JP2, JP3: STAND-OFF
JP4: LOGO-SFESK; SFE-LOGO-FLAME
JP5, JP6: FIDUCIAL1X2.5; FIDUCIAL-1X2.5
R1, R2: DNP; 0402-RES
U1: HMC5883LSMD; 16LPCC
U$1: CREATIVE_COMMONS
U$2: OSHW-LOGOM; OSHW-LOGO-M

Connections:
GND: C1.2, C3.2, JP1.1, U1.9 (GND), U1.11 (GND)
unnamed: C3.1, U1.10 (C1)
unnamed: C2.1, U1.8 (SETP)
unnamed: C2.2, U1.12 (SETC)
SCL: JP1.4, R1.1, U1.1 (SCL)
SDA: JP1.3, R2.1, U1.16 (SDA)
VCC: C1.1, JP1.2, R1.2, R2.2, U1.2 (VDD), U1.4 (S1), U1.13 (VDDIO)

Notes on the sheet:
Jordan McConnell
v12

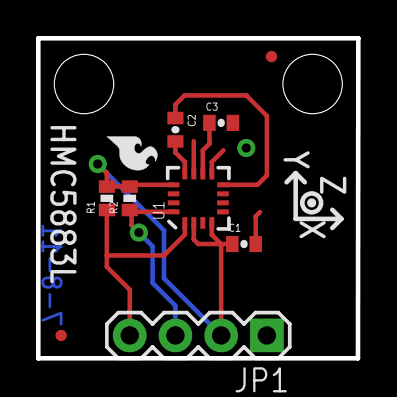
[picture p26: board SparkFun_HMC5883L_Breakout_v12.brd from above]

Board: 2 copper layers, 17.8 x 17.8 mm, 14 parts (1 on the bottom side), 7 nets.

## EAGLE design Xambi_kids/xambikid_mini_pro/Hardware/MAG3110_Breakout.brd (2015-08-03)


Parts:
C1, C2, C3, C5: 0.1uF; 0603-CAP
C4: 1uF; 0603-CAP
FID1, FID2: FIDUCIAL1X2; FIDUCIAL-1X2
FRAME2: FRAME-LETTER; CREATIVE_COMMONS
JP1: breakout; 1X05
JP2, JP3: STAND-OFF
JP7: LOGO-SFESK; SFE-LOGO-FLAME
LOGO1: OSHW-LOGOS; OSHW-LOGO-S
R1, R2: 4.7k; 0603-RES
SJ1: SOLDERJUMPER_2WAYPASTE1&2&3; SJ_3_PASTE1&2&3
U1: MAG31101:1; DFN-10-W

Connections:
GND: C1.2, C2.2, C3.2, C4.2, C5.2, JP1.1, U1.5 (GND), U1.10 (GND)
INT: JP1.5, U1.9 (INT1)
unnamed: C2.1, U1.4 (CAP-R)
unnamed: C1.1, U1.1 (CAP-A)
unnamed: R2.2, SJ1.1
unnamed: R1.2, SJ1.3
SCL: JP1.4, R2.1, U1.7 (SCL)
SDA: JP1.3, R1.1, U1.6 (SDA)
VCC: C3.1, C4.1, C5.1, JP1.2, SJ1.2, U1.2 (VDD), U1.8 (VDDIO)

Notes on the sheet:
Kade Jensen
Default pulled HIGH
Default 7-bit I2C Address: 0x0E



Board: 2 copper layers, 15.2 x 15.2 mm, 18 parts (3 on the bottom side), 9 nets.

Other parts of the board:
JP4: LOGO-SFESK; SFE-LOGO-FLAME

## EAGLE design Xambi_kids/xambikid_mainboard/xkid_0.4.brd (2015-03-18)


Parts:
ANT: ANTENNA; PAD-01
BOOST: MCP1640; SOT95P270X145-6N
BOOST_OFF: SJ
C1: 4.7mF; CT3216
C2, C3: 100nF; C0805K
C4, C5: 4.7mF; C0805K
CR2032: CR2032SMT; CR2032-SMD
IR: IR; LED3MM
JP1: PINHD-2X4_2.54; 2X04
L1: 4.7mH; 0204/5
R1: 200k; R0805
R2: 330k; R0805
R3: 100k; R0805
R4: 10K; R0805
R5: 300R; R0805
S1: SWITCH-MOMENTARY-2TACTILE-SWITCH-SMD-RIGHT-ANGLE; TACTILE_SWITCH-SMD-RIGHT-ANGLE
TINY84: ATTINY84ATTINY84-20MU; QFN20
U$1: RFM12_SMDSMD; RFM12
U$2: AVR-ISP-6-EDGE; 6PAD_ISP

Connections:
+3V3: C1.+, C3.2, CR2032.+$1 (+), CR2032.+$2 (+1), R3.2, R4.2, TINY84.9 (VCC), U$1.9 (VDD), U$2.VCC
ANT: ANT.1, U$1.8 (ANT)
ATNY_TX: IR.K (C), JP1.6, TINY84.11 ((PCINT8/XTAL1/CLKI)PB0)
BOOST_POWER: BOOST.5 (VOUT), BOOST_OFF.2, C2.2, C4.2, JP1.8, R2.2
GND: BOOST.2 (GND), C1.-, C2.1, C3.1, C4.1, C5.1, CR2032.-, JP1.7, R1.1, S1.2, TINY84.8 (GND), U$1.7 (GND), U$1.10 (GND), U$2.GND
IRQ: R5.1, TINY84.14 ((PCINT10/INT0/OC0A/CKOUT)PB2), U$1.2 (!IRQ)
unnamed: IR.A, R5.2
unnamed: BOOST.1 (SW), L1.1
unnamed: BOOST.4 (VFB), R1.2, R2.1
PA0: BOOST.3 (EN), BOOST.6 (VIN), BOOST_OFF.1, C5.2, JP1.5, L1.2, TINY84.5 ((PCINT0/AREF/ADC0)PA0)
PA1: JP1.4, TINY84.4 ((PCINT1/AIN0/ADC1)PA1)
PA2: JP1.3, TINY84.3 ((PCINT2/AIN1/ADC2)PA2)
PA3: JP1.2, TINY84.2 ((PCINT3/T0/ADC3)PA3)
PA7: JP1.1, TINY84.15 ((PCINT7/ICP/OC0B/ADC7)PA7)
RST: R4.1, S1.1, TINY84.13 ((PCINT11/~RESET/DW)PB3), U$2.RST
SCL: TINY84.1 ((PCINT4/T1/SCL/USCK/ADC4)PA4), U$1.13 (SCK), U$2.SCK
SDI: TINY84.20 ((PCINT5/OC1B/MISO/DO/ADC5)PA5), U$1.12 (SDI), U$2.MISO
SDO: TINY84.16 ((PCINT6/OC1A/SDA/MOSI/ADC6)PA6), U$1.1 (SDO), U$2.MOSI
SEL: R3.1, TINY84.12 ((PCINT9/XTAL2)PB1), U$1.14 (!SEL)

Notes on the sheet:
Xambi_kid an attiny84 low power with a coincell CR2032 and a RFM12B http://jeelabs.net/projects/hardware/wiki/JeeNode_Micro
Attention: Solder and Use IR Emitter only if you dont install an RFM12B Transceiver!
Attention: Power come over Pin PA0/D10/A0/AREF, this pin have to activate every time!



Board: 2 copper layers, 43.8 x 29.2 mm, 21 parts (15 on the bottom side), 19 nets.

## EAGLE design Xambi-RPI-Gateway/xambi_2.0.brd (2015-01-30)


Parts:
ANT1: 1,6/0,8
C4, C5, C7: 0.1uF; C0603
ICSP: AVR-ISP-6-EDGE; 6PAD_ISP
LED1: LEDSML0805; SML0805
R1: 10K; R0603
RASPBERRY_PI: FE05-2
RLED: 220R; R0805
U2: ATMEGA168; TQFP32-08
U$1: RFM12_SMDSMD; RFM12

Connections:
+3V3: C4.1, C7.1, ICSP.VCC, R1.2, RASPBERRY_PI.2, U2.4 (VCC), U2.6 (VCC), U2.18 (AVCC), U$1.9 (VDD)
A0: U2.23 (PC0(ADC0))
A1: U2.24 (PC1(ADC1))
A2: U2.25 (PC2(ADC2))
A3: U2.26 (PC3(ADC3))
A4/SDA: U2.27 (PC4(ADC4/SDA))
A5/SCL: U2.28 (PC5(ADC5/SCL))
A6: U2.19 (ADC6)
A7: U2.22 (ADC7)
D0/RX: RASPBERRY_PI.7, U2.30 (PD0(RXD))
D1/TX: RASPBERRY_PI.9, U2.31 (PD1(TXD))
D2: U2.32 (PD2(INT0)), U$1.2 (!IRQ)
D3: U2.1 (PD3(INT1))
D4: U2.2 (PD4(XCK/T0))
D5: U2.9 (PD5(T1))
D6: U2.10 (PD6(AIN0))
D7: U2.11 (PD7(AIN1))
D8: U2.12 (PB0(ICP))
D9: LED1.A, U2.13 (PB1(OC1A))
D10: U2.14 (PB2(SS/OC1B)), U$1.14 (!SEL)
D11/MOSI: ICSP.MOSI, U2.15 (PB3(MOSI/OC2)), U$1.1 (SDO)
D12/MISO: ICSP.MISO, U2.16 (PB4(MISO)), U$1.12 (SDI)
D13/SCK: ICSP.SCK, U2.17 (PB5(SCK)), U$1.13 (SCK)
GND: C4.2, C7.2, ICSP.GND, RASPBERRY_PI.5, RASPBERRY_PI.10, RLED.1, U2.3 (GND), U2.5 (AGND), U2.21 (GND), U$1.7 (GND), U$1.10 (GND)
unnamed: LED1.C, RLED.2
unnamed: ANT1.1, U$1.8 (ANT)
RESET: C5.2, ICSP.RST, R1.1, U2.29 (PC6(/RESET))
_RESET: C5.1, RASPBERRY_PI.8

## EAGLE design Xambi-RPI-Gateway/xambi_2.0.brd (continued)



Board: 2 copper layers, 27.8 x 20.6 mm, 11 parts (5 on the bottom side), 14 nets.

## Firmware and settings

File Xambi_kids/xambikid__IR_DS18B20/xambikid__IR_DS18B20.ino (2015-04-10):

//----------------------------------------------------------------------------------------------------------------------
// XAmbiKid/DS18B20 - An ATtiny84 and RFM12B Wireless Temperature Sensor Node
// By Frank Herrmann. For hardware design see http://xpix.de
//
// Licenced under the Creative Commons Attribution-ShareAlike 3.0 Unported (CC BY-SA 3.0) licence:
// http://creativecommons.org/licenses/by-sa/3.0/
//
// Requires Arduino IDE with arduino-tiny core: http://code.google.com/p/arduino-tiny/
//
// !!! Use the Infrared Communication with a gateway with installed TSOP !!!
//
// For Attiny8* please check this:
// http://www.ernstc.dk/arduino/38khz_timer.htm
//
//----------------------------------------------------------------------------------------------------------------------

#include <JeeLib.h> // https://github.com/jcw/jeelib
#include "xambikid_tools.h"

#include <OneWire.h>
#include <DallasTemperature.h>

//#define USE_ACK           // Enable ACKs, comment out to disable

// Node defines
#define network 100       // RF12 Network group (IR == 100)
#define myNodeID 1        // RF12 node ID in the range 1-30
#define mySubNodeID 15    // RF12 subnode ID (Please check config file: cfg/sensortypes.cfg)
#define myParamsSize 1    // How much values want to send (supplyV, value1, value2) = 3

#define IR_A   9           // Powerpin for IR LED
#define IR_B  10           // Alternative Powerpin for IR LED
#define LED   13           // Flash for debug

// Sensor defines
#define ONE_WIRE_BUS 3   // DS18B20 Temperature sensor is connected o0qn D10/ATtiny pin 13
#define ONE_WIRE_POWER 0  // DS18B20 Power pin is connected on D0/ATtiny pin 2

OneWire oneWire(ONE_WIRE_BUS); // Setup a oneWire instance
DallasTemperature sensors(&oneWire); // Pass our oneWire reference to Dallas Temperature

// Data Structure to be sent
struct Payload_s{
  byte subnode;       // Subnode Id (standard value)
  byte paramsize;     // parameters size
  int supplyV;	      // Supply voltage (standard value)
  int temp;	      // moisture reading
} Payload_default  = {mySubNodeID, myParamsSize, 0, 0}; // Default Values!!
typedef struct Payload_s Payload;
Payload tinytx = Payload_default;
// --------------------------


void setup() {
  pinMode(IR_A, OUTPUT);
  pinMode(IR_B, OUTPUT);
  pinMode(ONE_WIRE_POWER, OUTPUT); // set power on for sensor
  
  //tools_init_rf24(myNodeID, network);

  // IR send logic with 38khz Carrier and 2400 baud
  // 
  // Clear Timer on Compare Match (CTC) Mode
  bitWrite(TCCR1A, WGM10, 0);
  bitWrite(TCCR1A, WGM11, 0);
  bitWrite(TCCR1B, WGM12, 1);
  bitWrite(TCCR1B, WGM13, 0);

  // Toggle OC1A and OC1B on Compare Match.
  bitWrite(TCCR1A, COM1A0, 1);
  bitWrite(TCCR1A, COM1A1, 0);
  bitWrite(TCCR1A, COM1B0, 1);
  bitWrite(TCCR1A, COM1B1, 0);

  // No prescaling
  bitWrite(TCCR1B, CS10, 1);
  bitWrite(TCCR1B, CS11, 0);
  bitWrite(TCCR1B, CS12, 0);

  OCR1A = 210;
  OCR1B = 210;
  
  Serial.begin(1200);
}

void loop() {
   digitalWrite(ONE_WIRE_POWER, HIGH); // turn DS18B20 sensor on
   digitalWrite(LED, HIGH);  // turn led on
   delay(50); // only a flash
   // Measure Power for solar low power nodes with super cap
   // The Node switch on at ~1.8V. This is not enough for 
   // the RFM12B (need min 2.2V). Wait for enough saved 
   // solar power from supercap
   tinytx.supplyV = tools_readVcc(); // Get supply voltage
   digitalWrite(LED, LOW);  // turn led off
   
   delay(5); // The above doesn't seem to work for everyone (why?)
   
   sensors.begin(); //start up temp sensor
   sensors.requestTemperatures(); // Get the temperature
   tinytx.temp=(sensors.getTempCByIndex(0)*100); // Read first sensor and convert to integer, reversed at receiving end
   tinytx.paramsize = myParamsSize;   
   
   digitalWrite(ONE_WIRE_POWER, LOW); // turn DS18B20 off
   
   // tools_rfwrite(myNodeID, &tinytx, sizeof tinytx); // Send data via RF 
   // emulate RF send string
   // i.e.:  112 1 2987 1806
   Serial.print(myNodeID);      // 1
   Serial.print(mySubNodeID);   // 12
   Serial.print(' ');
   Serial.print(myParamsSize);  // 1
   Serial.print(' ');
   Serial.print(tinytx.supplyV);// 2987
   Serial.print(' ');
   Serial.print(tinytx.temp);    // 1806
   Serial.println();

   Sleepy::loseSomeTime(10000); //JeeLabs power save function: enter low power mode for 60 seconds (valid range 16-65000 ms)
}

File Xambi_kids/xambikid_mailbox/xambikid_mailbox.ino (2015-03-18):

//----------------------------------------------------------------------------------------------------------------------
// XAmbiKid/Mailbox - An ATtiny84 and RFM12B Wireless Mailbox Node
// By Frank Herrmann. For hardware design see http://xpix.de
//
// Licenced under the Creative Commons Attribution-ShareAlike 3.0 Unported (CC BY-SA 3.0) licence:
// http://creativecommons.org/licenses/by-sa/3.0/
//
// Requires Arduino IDE with arduino-tiny core: http://code.google.com/p/arduino-tiny/
//
// Please check http://forum.arduino.cc/index.php?topic=101156.0 for simple schematic and function
//----------------------------------------------------------------------------------------------------------------------

#include <JeeLib.h> // https://github.com/jcw/jeelib
#include "xambikid_tools.h"
#include <SensorOp.h>
#include <EEPROM.h>

//#define USE_ACK           // Enable ACKs, comment out to disable

// Node defines
#define network 210       // RF12 Network group
#define myNodeID 4        // RF12 node ID in the range 1-30
#define mySubNodeID 11    // RF12 subnode ID (Please check config file: cfg/sensortypes.cfg)
#define myParamsSize 2    // How much values want to send (supplyV, value1, value2) = 3

#define LED 3            // Powerpin from IR-LED
#define SENSOR A1        // Sensorpin on Fototransistor
#define THRESHOLD 30     // Threshold for full
#define SAMPLES 4

// Sensor defines
SensorOp sensor(LED, SENSOR, SAMPLES);

bool full = false;
int sensor_dark = -1;
unsigned int minutes = 0;

// Data Structure to be sent
struct Payload_s{
  byte subnode;       // Subnode Id (standard value)
  byte paramsize;     // parameters size
  int supplyV;	      // Supply voltage (standard value)
  int box;	      // box event
  int val;	      // for debug
} Payload_default  = {mySubNodeID, myParamsSize, 0, 0, 0}; // Default Values!!
typedef struct Payload_s Payload;
Payload tinytx = Payload_default;
// --------------------------


void setup() {
#ifdef USE_ACK
  ack(1); // enable use ack
#endif
  Serial.begin(9600);
  Serial.println("Init...");
  pinMode(LED, OUTPUT);       // set power on for led

  tools_init_rf24(myNodeID, network);
  delay(10000);

  // only for tests
  // sensor_dark = calibration();

  Serial.println("Start Loop...");
}

void loop() {
   // wake up every minute and inc 
   minutes++;

   // If Box empty then Calibrate every 60min
   // don't calibrate if box full!
   if(minutes % 60 == 0){
      if( full == false ){
         sensor_dark = calibration();
      }
   }
   
   // Start sensor if he calibrated
   // temp difference between inside and outside 
   // let the electronic jitter
   // check every 5min
   if(minutes % 5 == 0){
     // after 5 min calibrate if sensor just switched on
     if(sensor_dark == -1){
         sensor_dark = calibration();
     }

     // Start sensor measure process
     tools_enable_adc();
     led_on();  // turn led on
     int sensorValue = sensor.readSensor();
     tinytx.val = (sensorValue - sensor_dark); // Get diff sensor value
     // Measure Power under power
     tinytx.supplyV = tools_readVcc(); // Get supply voltage
     led_off();  // turn led off
     tools_disable_adc();
  
     Serial.println(sensorValue);
     
     // empty or full
     full = false;
     if(sensorValue > (sensor_dark + THRESHOLD) || sensorValue < (sensor_dark - THRESHOLD)){
        full = true;
     }
  
     if(full == true){
       // Event, Box was filled!
       tinytx.box = 1;
       Serial.println("Send full");
       //tools_rfwrite(myNodeID, &tinytx, sizeof tinytx); // Send data via RF 
     }
     if(full == false){
       // Event, Box was emptied!
       tinytx.box = 0;
       Serial.println("Send empty");
       //tools_rfwrite(myNodeID, &tinytx, sizeof tinytx); // Send data via RF 
     }
  
     // for debug send data every minute
     tools_rfwrite(myNodeID, &tinytx, sizeof tinytx); // Send data via RF 
   }

   Sleepy::loseSomeTime(60000); //JeeLabs power save function: enter low power mode for 60 seconds (valid range 16-65000 ms)
}

void led_on(){
   digitalWrite(LED, HIGH);  // turn led on
   delay(5); // only a flash
}

void led_off(){
   digitalWrite(LED, LOW);  // turn led off
}

int calibration(){
  // Calibration
  int calib=0;

  Serial.println("Calibrierung...");
  tools_enable_adc();
  led_on();
  calib += sensor.readSensor();
  delay(50);
  calib += sensor.readSensor();
  delay(200);
  calib += sensor.readSensor();
  led_off();
  tools_disable_adc();

  int result = calib/3;
  return result;
}

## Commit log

2014-08-18 Init commit
    [Funky_3D_model.skp, funky_super_usb_r2.brd, funky_super_usb_r2.sch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]
2015-01-08 Lot of updates
    [xambi_2.0-bcream.dxf, xambi_2.0-tcream.dxf, xambi_2.0.brd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]
2015-01-30 Lot of updates and new sensors
    - new mailbox sensor
    - update sensor mainboard
    - update sensor board
    [xambi.GBL, xambi.GBO, xambi.GBP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]
2015-01-30 Move old file to zip
    [xkid_0.1.brd, xkid_0.1.sch, xkid_0.2-bcream.dxf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]
2015-01-30 Remove some unused files
    [xambi_2.0.sch]
2015-02-02 add example schematic template for sensorboards
    [template_sensorboard.sch]
2015-02-02 Iniz readme for moisture board
2015-02-02 update example schema
    [template_sensorboard.sch]
2015-02-03 Fixes for mailbox and moisture sensor
    Change Threshold to 75 and calibrate every 15min and only 3 samples.
    Changes wait for minutes in moisture
    [xambikid_mailbox.ino, xambikid_moisture.ino]
2015-02-16 Last fixes for mailbox sensor
    - break 15 min and measure then (outside temp)
    - Threshold change to 40
    - display difference between calibration and measure value as second
    param
    [xambikid_mailbox.ino]
2015-03-02 fix and add docu for DS18B20
    [xambikid_mailbox.ino]
2015-03-02 add schematic for DHT11 Sensor
2015-03-03 - mailbox sensor doc and images
2015-03-03 Move not finished or ideas to prototype folder
    [Funky_3D_model.skp, funky_super_usb_r2.brd, funky_super_usb_r2.sch]
2015-03-03 change template for sensor images
    [template_sensorboard.sch]
2015-03-03 - pic prototype
2015-03-03 - Move all gateway stuff to extra directory
    [xambi.brd, xambi.sch, xambi_1.0-bcream.dxf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]
2015-03-05 - add some pics for doku revert to jeelab
    [xambikid_mailbox_ino_tmp.ino]
2015-03-06 - fix first call
    [xambikid_mailbox.ino]
2015-03-06 - Add readme and pics to new board with booster and infrared
    [xkid_0.4.brd, xkid_0.4.sch]
2015-03-18 add booster to mainboard, add IR LED for ir communication
    [xkid_0.4.brd, xkid_0.4.sch]
2015-08-03 Add new board for Xambi Arduino Mini Pro
    Add example for esp8266-wifi370
    Add some examples for
    [Arduino-Pro-Mini-xkid-bcream.dxf, Arduino-Pro-Mini-xkid-tcream.dxf, Arduino-Pro-Mini-xkid.brd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]

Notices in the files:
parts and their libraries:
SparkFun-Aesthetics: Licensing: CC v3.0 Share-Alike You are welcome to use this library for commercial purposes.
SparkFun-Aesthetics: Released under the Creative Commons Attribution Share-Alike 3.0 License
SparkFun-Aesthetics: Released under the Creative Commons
